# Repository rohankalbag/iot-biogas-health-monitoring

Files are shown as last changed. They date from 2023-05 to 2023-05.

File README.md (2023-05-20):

# IoT-based Biogas Plant Health Monitoring
 
## EE-344 : Electronics Design Lab

- *An IoT-based monitoring system for a biogas plant that measures and displays parameters such as gas concentrations, humidity, and temperature* 

- *The design consists of a tailor-made custom in-house designed two-layer printed circuit board interfacing gas sensors in a modular fashion using I2C*

- *The data is sent to a central server and stored in a cloud database for remote access and analysis through a web application. The system helps optimize biogas production, identify issues, improve safety, and offers flexibility to integrate additional gas sensors. Furthermore, we successfully addressed anticipated problems during development and prototyping stages and submitted a complete market-ready product*

plant_sys

pcb

## [Link to Video Demonstrations](https://youtube.com/playlist?list=PLU3_Wxvmc-mbm3Yfq669lL-GAWkqmuRJW)

## [Link to Detailed Report](https://github.com/rohankalbag/iot-biogas-health-monitoring/blob/chusaro/Report.pdf)

## Recipient of "Best Project Award"

award

## Contributors : Team TUE-23 : Project 18
- Jujhaar Singh
- Sankalp Bhamare
- Rohan Rajesh Kalbag

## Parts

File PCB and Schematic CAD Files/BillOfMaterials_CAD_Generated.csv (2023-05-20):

Part | Value | Device | Package | Description | AVAILABILITY | CATEGORY | CONTACTS | CURRENT_RATING | DESCRIPTION | GENDER | MANUFACTURER | MAXIMUM_PACKAGE_HEIGHT | MF | MOUNT_TYPE | MP | MPN | OPERATING_TEMP | PACKAGE | PARTREV | PART_STATUS | PRICE | ROHS_COMPLIANT | SERIES | SNAPEDA_PACKAGE_ID | SNAPEDA_PN | STANDARD | SUB-CATEGORY | TYPE | VOLTAGE_RATING
C1 | 100nF | CAPACITOR_SMD_1206 | C1206
C2 | 100nF | CAPACITOR_SMD_1206 | C1206
C3 | 100nF | CAPACITOR_SMD_1206 | C1206
C4 | 100nF | CAPACITOR_SMD_1206 | C1206
C5 | 100nF | CAPACITOR_SMD_1206 | C1206
C6 | 100nF | CAPACITOR_SMD_1206 | C1206
C9 | 100nF | CAPACITOR_SMD_1206 | C1206
C10 | 100nF | CAPACITOR_SMD_1206 | C1206
C11 | 100nF | CAPACITOR_SMD_1206 | C1206
C12 | 100nF | CAPACITOR_SMD_1206 | C1206
J1 | 61729-1011 | 61729-1011 | 61729-1011BLF | USB(2.0) Type-B, RCPT, 4POS, THT-R/A |  | Connector | 4 | 1A | CONN RCPT USB2.0 TYPEB 4POS R/A | Receptacle | Amphenol ICC (FCI) |  |  | R/A |  | 61729-1011BLF | -55°C to 85°C |  |  | Active |  | RoHS Compliant | 61729 |  |  |  | USB | USB-B
J2 | 1722991304 | 1722991304 | MOLEX_1722991304 |  |  |  |  |  |  |  | Molex | 14.0 mm |  |  |  |  |  |  | B8 |  |  |  |  |  |  | Manufacturer Recommendations
J3 | 1722991304 | 1722991304 | MOLEX_1722991304 |  |  |  |  |  |  |  | Molex | 14.0 mm |  |  |  |  |  |  | B8 |  |  |  |  |  |  | Manufacturer Recommendations
J4 | 1722991304 | 1722991304 | MOLEX_1722991304 |  |  |  |  |  |  |  | Molex | 14.0 mm |  |  |  |  |  |  | B8 |  |  |  |  |  |  | Manufacturer Recommendations
J5 | 1722991304 | 1722991304 | MOLEX_1722991304 |  |  |  |  |  |  |  | Molex | 14.0 mm |  |  |  |  |  |  | B8 |  |  |  |  |  |  | Manufacturer Recommendations
LS1 | PS1240P02BT | PS1240P02BT | XDCR_PS1240P02BT | Buzzers Transducer, Externally Driven Piezo 3V 4kHz 60dB @ 3V, 10cm Through Hole PC Pins | Unavailable |  |  |  | Buzzers Transducer, Externally Driven Piezo 3V 4kHz 60dB @ 3V, 10cm Through Hole PC Pins |  |  | 7.0mm | TDK |  | PS1240P02CT3 |  |  | SIP-5 TDK |  |  | None
Q1 | BSS138 | BSS138 | SOT95P240X111-3N | N-Channel 50V 220mA (Ta) 360mW (Ta) Surface Mount SOT-23-3 |  |  |  |  |  |  | ON Semiconductor | 1.11 mm |  |  |  |  |  |  | 30 Jan 2018 |  |  |  |  |  |  | IPC 7351B
Q2 | BSS138 | BSS138 | SOT95P240X111-3N | N-Channel 50V 220mA (Ta) 360mW (Ta) Surface Mount SOT-23-3 |  |  |  |  |  |  | ON Semiconductor | 1.11 mm |  |  |  |  |  |  | 30 Jan 2018 |  |  |  |  |  |  | IPC 7351B
Q3 | BSS138 | BSS138 | SOT95P240X111-3N | N-Channel 50V 220mA (Ta) 360mW (Ta) Surface Mount SOT-23-3 |  |  |  |  |  |  | ON Semiconductor | 1.11 mm |  |  |  |  |  |  | 30 Jan 2018 |  |  |  |  |  |  | IPC 7351B
R1 | 10k | RESISTOR_SMD_1206 | M1206
R2 | 1K | RESISTOR_SMD_1206 | M1206
R3 | 1k | RESISTOR_SMD_1206 | M1206
R4 | 10k | RESISTOR_SMD_1206 | M1206
R5 | 470E | RESISTOR_SMD_1206 | M1206
R6 | 470E | RESISTOR_SMD_1206 | M1206
R7 | 470E | RESISTOR_SMD_1206 | M1206
R8 | 10k | RESISTOR_SMD_1206 | M1206
R9 | 10k | RESISTOR_SMD_1206 | M1206
R10 | 10k | RESISTOR_SMD_1206 | M1206
R11 | 10k | RESISTOR_SMD_1206 | M1206
R12 | 10k | RESISTOR_SMD_1206 | M1206
R13 | 10k | RESISTOR_SMD_1206 | M1206
R14 | 10k | RESISTOR_SMD_1206 | M1206
R15 | 10k | RESISTOR_SMD_1206 | M1206
S3 | TS04-66-55-BK-260-SMT | TS04-66-55-BK-260-SMT | SW_TS04-66-55-BK-260-SMT |  |  |  |  |  |  |  | CUI Devices |  |  |  |  |  |  |  | 1.0 |  |  |  |  |  |  | Manufacturer Recommendations
S4 | TS04-66-55-BK-260-SMT | TS04-66-55-BK-260-SMT | SW_TS04-66-55-BK-260-SMT |  |  |  |  |  |  |  | CUI Devices |  |  |  |  |  |  |  | 1.0 |  |  |  |  |  |  | Manufacturer Recommendations
T1 | BC847 | BC847 | SOT23 | NPN TRANSISTOR
T2 | BC847 | BC847 | SOT23 | NPN TRANSISTOR
U1 | ESP32-WROOM-32 | ESP32-WROOM-32 | MODULE_ESP32-WROOM-32 |  |  |  |  |  |  |  | Espressif Systems | 3.2 mm |  |  |  |  |  |  | 2.9 |  |  |  |  |  |  | Manufacturer Recommendations
U2 | AMS1117-3.3 | AMS1117-3.3 | SOT229P700X180-4N |  |  |  |  |  |  |  | Advanced Monolithic Systems | 1.8 mm |  |  |  |  |  |  | N/A |  |  |  |  | 71280 | AMS1117-3.3 | IPC 7351B
U3 | CH340G | CH340G | SOIC127P600X180-16N |  |  |  |  |  |  |  | WCH | 1.8 mm |  |  |  |  |  |  | 2G |  |  |  |  |  |  | IPC 7351B

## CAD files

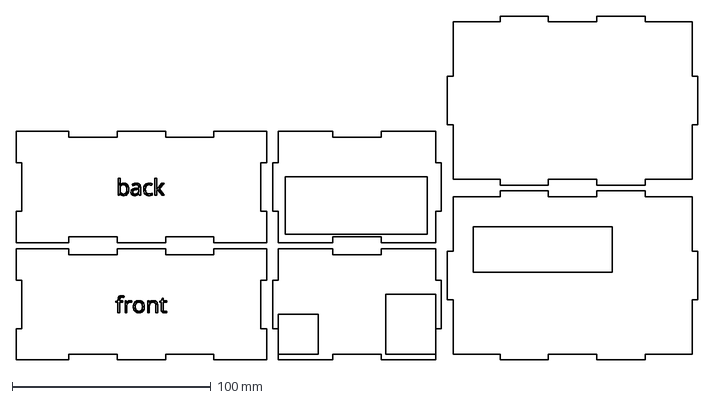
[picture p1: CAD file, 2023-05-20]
Enclosure CAD Files/TUES-23-ENCLOSURE.dxf
343.0 x 173.0 mm

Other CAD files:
Enclosure CAD Files/TUES-23-ENCLOSURE.f3d

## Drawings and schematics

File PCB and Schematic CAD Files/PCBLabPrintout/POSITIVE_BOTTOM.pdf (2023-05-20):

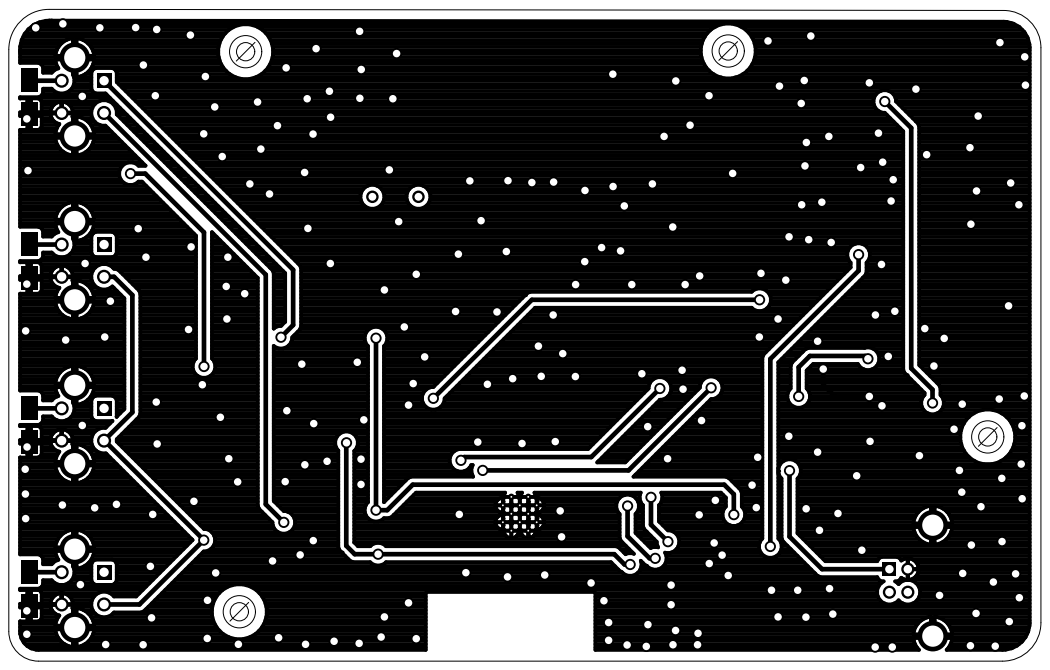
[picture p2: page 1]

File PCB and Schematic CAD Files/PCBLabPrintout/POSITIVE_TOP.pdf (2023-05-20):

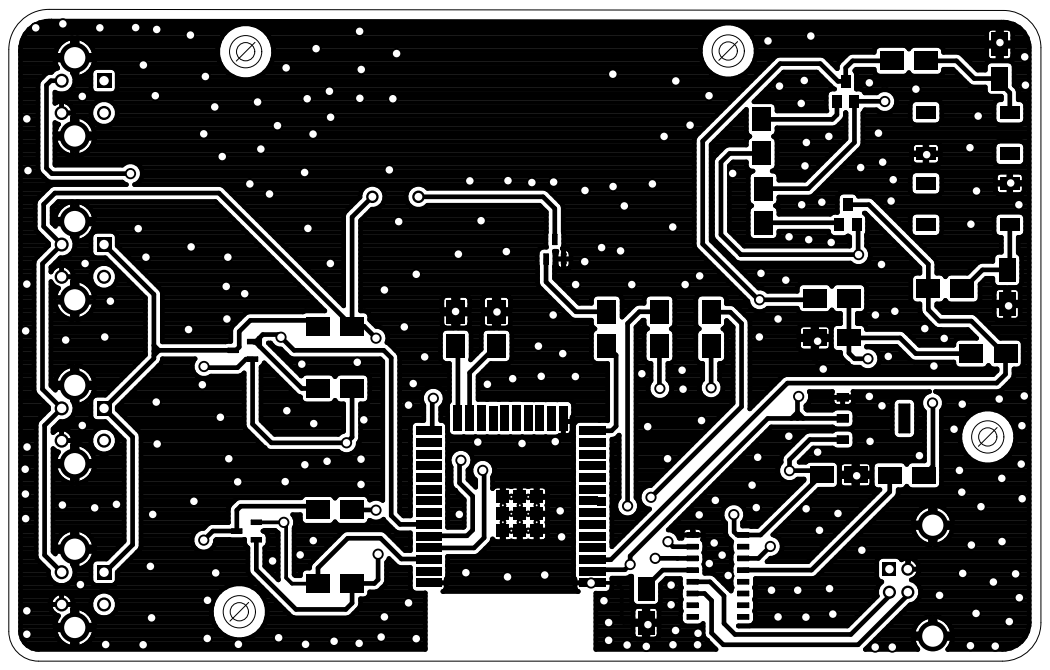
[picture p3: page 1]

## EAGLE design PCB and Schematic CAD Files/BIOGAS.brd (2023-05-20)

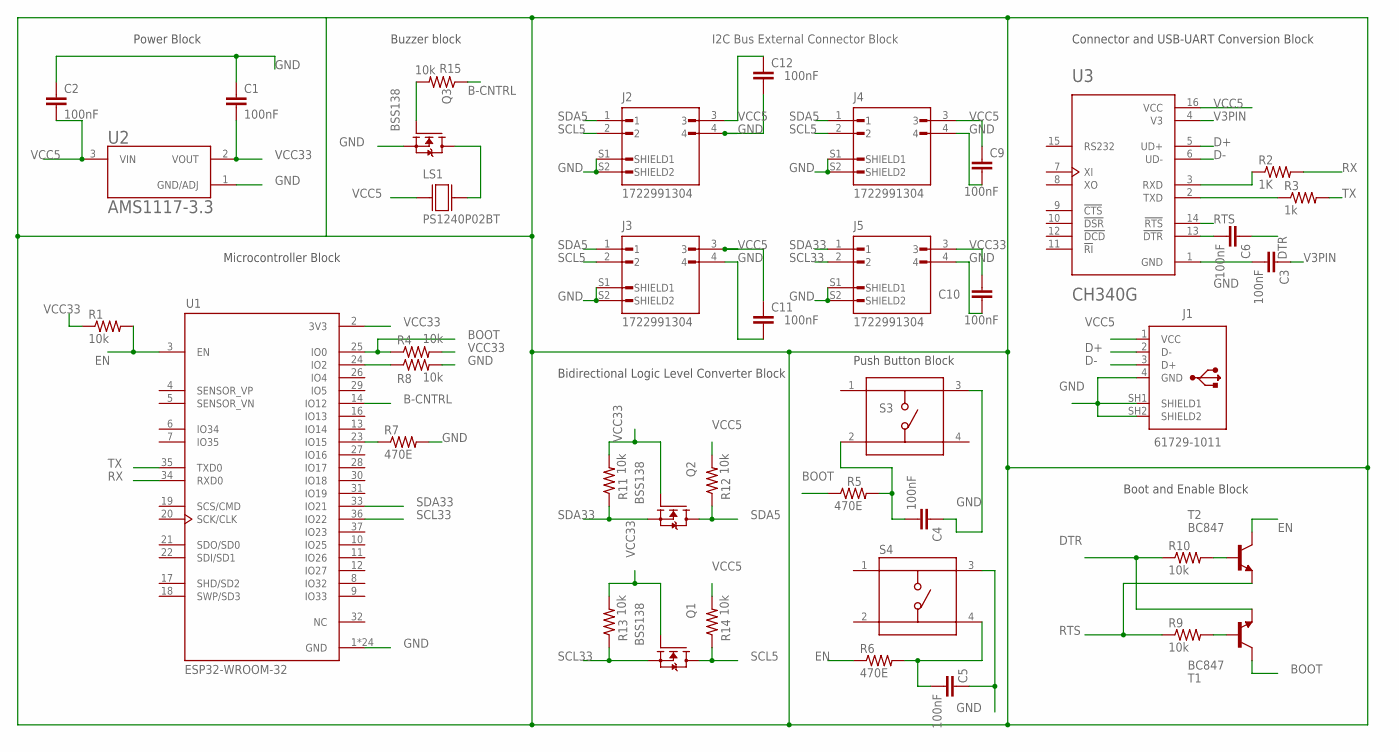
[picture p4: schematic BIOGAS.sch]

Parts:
C1, C2, C3, C4, C5, C6, C9, C10, C11, C12: 100nF; C1206
J1: 61729-1011; 61729-1011BLF
J2, J3, J4, J5: 1722991304; MOLEX_1722991304
LS1: PS1240P02BT; XDCR_PS1240P02BT
Q1, Q2, Q3: BSS138; SOT95P240X111-3N
R1, R4, R8, R9, R10, R11, R12, R13, R14, R15: 10k; M1206
R2: 1K; M1206
R3: 1k; M1206
R5, R6, R7: 470E; M1206
S3, S4: TS04-66-55-BK-260-SMT; SW_TS04-66-55-BK-260-SMT
T1, T2: BC847; SOT23
U1: ESP32-WROOM-32; MODULE_ESP32-WROOM-32
U2: AMS1117-3.3; SOT229P700X180-4N
U3: CH340G; SOIC127P600X180-16N

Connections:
B-CNTRL: R15.1, U1.14 (IO12)
BOOT: R4.1, R5.1, T1.3 (C), U1.25 (IO0)
D+: J1.2 (D-), U3.5 (UD+)
D-: J1.3 (D+), U3.6 (UD-)
DTR: C6.1, R10.1, T1.2 (E)
EN: R1.2, R6.1, T2.3 (C), U1.3 (EN)
GND: C1.1, C2.1, C3.2, C4.1, C5.1, C9.2, C10.2, C11.2, C12.2, J1.4 (GND), J1.SH1 (SHIELD1), J1.SH2 (SHIELD2), J2.4, J2.S1 (SHIELD1), J2.S2 (SHIELD2), J3.4, J3.S1 (SHIELD1), J3.S2 (SHIELD2), J4.4, J4.S1 (SHIELD1), J4.S2 (SHIELD2), J5.4, J5.S1 (SHIELD1), J5.S2 (SHIELD2), Q3.2 (S), R7.2, R8.2, S3.3, S4.3, U1.1 (GND), U1.15 (GND), U1.38 (GND), U1.39_1 (GND), U1.39_2 (GND), U1.39_3 (GND), U1.39_4 (GND), U1.39_5 (GND), U1.39_6 (GND), U1.39_7 (GND), U1.39_8 (GND), U1.39_9 (GND), U1.39_10 (GND), U1.39_11 (GND), U1.39_12 (GND), U1.39_13 (GND), U1.39_14 (GND), U1.39_15 (GND), U1.39_16 (GND), U1.39_17 (GND), U1.39_18 (GND), U1.39_19 (GND), U1.39_20 (GND), U1.39_21 (GND), U2.1 (GND/ADJ), U3.1 (GND)
unnamed: R8.1, U1.24 (IO2)
unnamed: R2.1, U3.3 (RXD)
unnamed: R3.1, U3.2 (TXD)
unnamed: C4.2, R5.2, S3.2
unnamed: C5.2, R6.2, S4.4
unnamed: R7.1, U1.23 (IO15)
unnamed: C6.2, U3.13 (!DTR)
unnamed: R10.2, T2.1 (B)
unnamed: R9.2, T1.1 (B)
unnamed: LS1.2, Q3.3 (D)
unnamed: Q3.1 (G), R15.2
RTS: R9.1, T2.2 (E), U3.14 (!RTS)
RX: R2.2, U1.34 (RXD0)
SCL5: J2.2, J3.2, J4.2, Q1.3 (D), R14.1
SCL33: J5.2, Q1.2 (S), R13.1, U1.36 (IO22)
SDA5: J2.1, J3.1, J4.1, Q2.3 (D), R12.1
SDA33: J5.1, Q2.2 (S), R11.1, U1.33 (IO21)
TX: R3.2, U1.35 (TXD0)
V3PIN: C3.1, U3.4 (V3)
VCC5: C2.2, C9.1, C11.1, C12.1, J1.1 (VCC), J2.3, J3.3, J4.3, LS1.1, R12.2, R14.2, U2.3 (VIN), U3.16 (VCC)
VCC33: C1.2, C10.1, J5.3, Q1.1 (G), Q2.1 (G), R1.1, R4.2, R11.2, R13.2, U1.2 (3V3), U2.2 (VOUT)

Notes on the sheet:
Bidirectional Logic Level Converter Block
Boot and Enable Block
Connector and USB-UART Conversion Block
I2C Bus External Connector Block
Power Block
Microcontroller Block
Push Button Block
Buzzer block

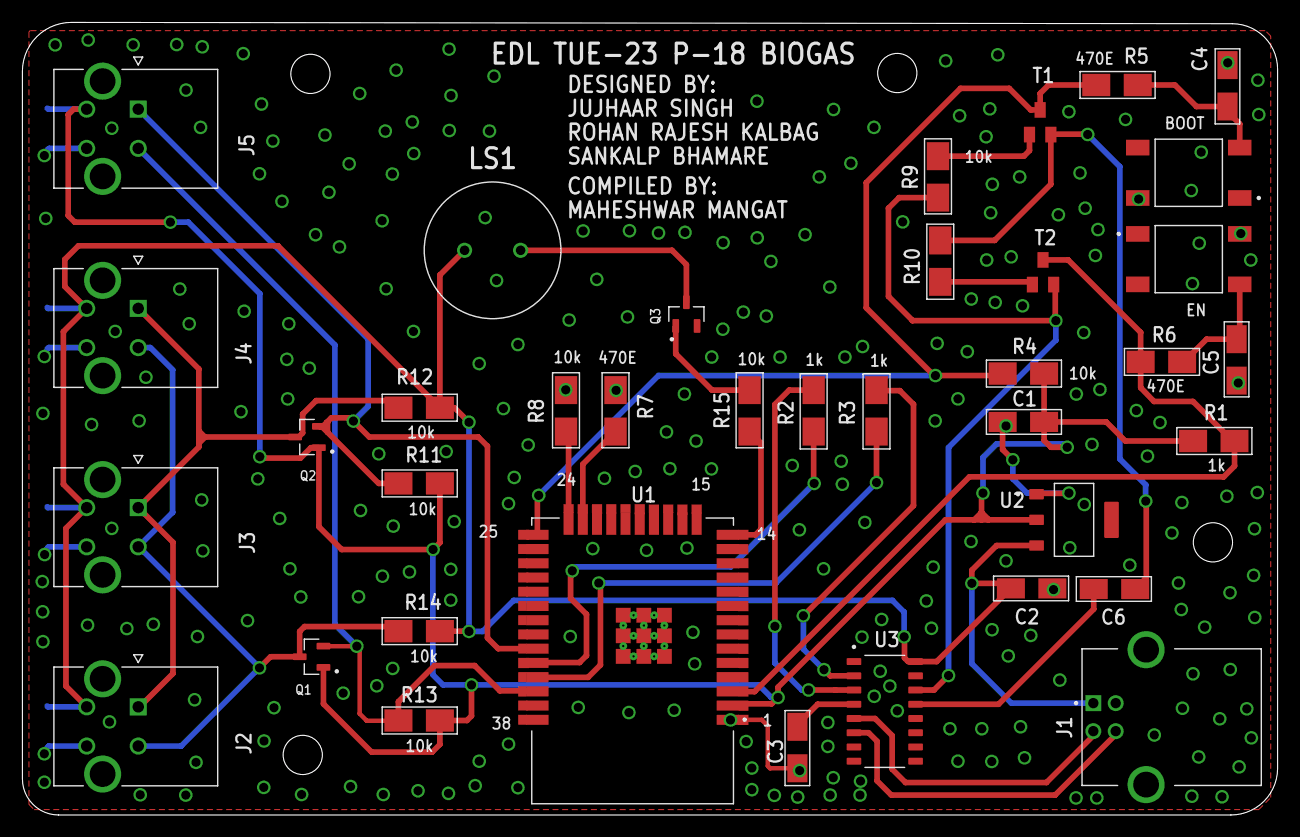
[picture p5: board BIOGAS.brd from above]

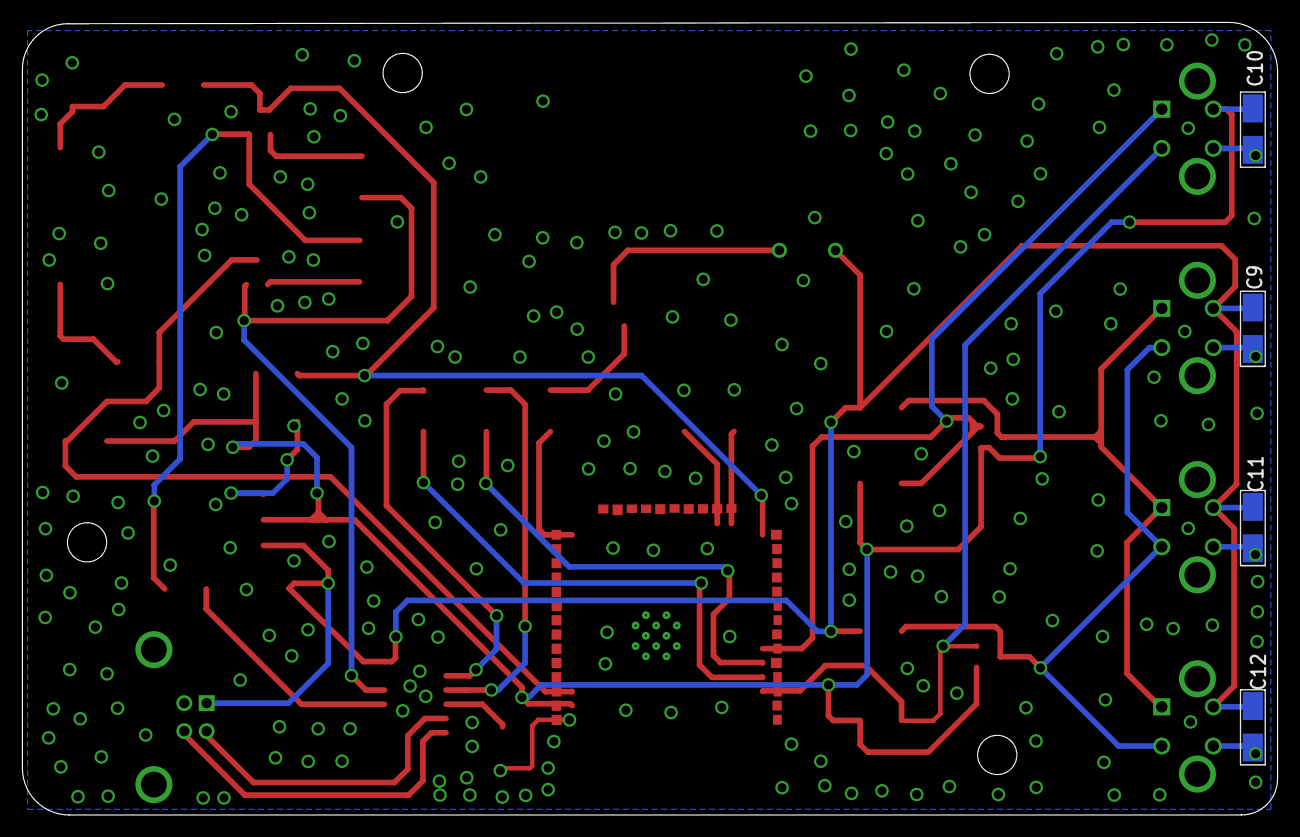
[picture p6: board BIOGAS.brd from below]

Board: 2 copper layers, 112.0 x 70.7 mm, 41 parts (4 on the bottom side), 28 nets.

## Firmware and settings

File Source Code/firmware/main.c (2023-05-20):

// Electronic Design Lab EE 344 IIT Bombay
// Team Tue: 23 
// Authors: Sankalp Bhamare, Rohan Rajesh Kalbag, Jujhaar Singh

#include "server_conn.h"
#include "drivers/i2c_conn.h"

// sensor threshold value, sensor rings after co2 value exceeds threshold

#define SENSOR_THRESHOLD 3000

static const char *TAG = "BioGAS";

void app_main(void)
{
    esp_err_t ret;
    ret = nvs_flash_init();
    if (ret == ESP_ERR_NVS_NO_FREE_PAGES || ret == ESP_ERR_NVS_NEW_VERSION_FOUND)
    {
        ESP_ERROR_CHECK(nvs_flash_erase());
        ret = nvs_flash_init();
    }
    ESP_LOGI(TAG, "SYSTEM BOOTED");

    ESP_LOGI(TAG, "I2C init start");
    init_i2c();
    ESP_LOGI(TAG, "Connecting LCD....");
    init_lcd();
    ESP_LOGI(TAG, "LCD CONNECTED");
    begin_lcd();

    // Basic User Interface on the LCD

    printstr_lcd("EDL P-18");
    setCursor_lcd(0, 1);
    printstr_lcd("TUE-23");
    vTaskDelay(2000 / portTICK_PERIOD_MS);
    setCursor_lcd(0, 1);
    printstr_lcd("Sankalp");
    vTaskDelay(2000 / portTICK_PERIOD_MS);
    setCursor_lcd(0, 1);
    printstr_lcd("Jujhaar");
    vTaskDelay(2000 / portTICK_PERIOD_MS);
    setCursor_lcd(0, 1);
    printstr_lcd("Rohan   ");
    vTaskDelay(2000 / portTICK_PERIOD_MS);

    setCursor_lcd(0, 1);
    printstr_lcd("WiFi Init..");

    ESP_LOGI(TAG, "initializing WiFi module.");
    ret = wifi_init_sta();
    
    if (ret != ESP_OK)
    {
        ESP_LOGE(TAG, "WiFi initialization failed!");
        for (;;)
        {}
    }

    // After WiFi connection is established
    setCursor_lcd(0, 1);
    printstr_lcd("WiFi Connected");

    vTaskDelay(4000 / portTICK_PERIOD_MS);

    setCursor_lcd(0, 1);
    printstr_lcd("System Start");

    vTaskDelay(4000 / portTICK_PERIOD_MS);
    ESP_LOGI(TAG, "WiFi module initialized.");

    // uncomment below line if you want to use LCD backlight
    // backlight_lcd(); 

    init_buzzer(); // initialize buzzer
    for (;;)
    {
        // read co2 sensor data
        int co2_ppm = read_co2_ppm();
        // conditional to check if the sensor reading is under threshold
        if (co2_ppm > SENSOR_THRESHOLD)
        {
            buzzer_toggle(true);
        }
        else
        {
            buzzer_toggle(false);
        }

        double temp, rel_humidity;
        // read the dht sensor values
        read_dht(&rel_humidity, &temp);
        // send sensor readings to web server
        render_screen(co2_ppm, rel_humidity);
        http_post_task(co2_ppm, rel_humidity);
        ESP_LOGI(TAG, "HTTP DATA PUSHED");
    }
    denit_i2c();
    vTaskDelay(10);
}

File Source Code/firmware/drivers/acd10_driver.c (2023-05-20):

// Electronic Design Lab EE 344 IIT Bombay
// Team Tue: 23 
// Authors: Sankalp Bhamare, Rohan Rajesh Kalbag, Jujhaar Singh

// drivers for the acd10 co2 sensor

#include "acd10_driver.h"

int read_co2_ppm()
{ 
  // function to read the co2 sensor readings
  uint8_t read_cmd[2] = {0x03, 0x00};

  uint8_t i2c_buffer_out[9];
  char buffer_out[9];
  ESP_ERROR_CHECK(i2c_master_write_to_device(I2C_MASTER_NUM, ACD_ADDRESS, read_cmd, 2, I2C_MASTER_TIMEOUT_MS / portTICK_PERIOD_MS));
  ESP_ERROR_CHECK(i2c_master_read_from_device(I2C_MASTER_NUM, ACD_ADDRESS, i2c_buffer_out, 9, I2C_MASTER_TIMEOUT_MS / portTICK_PERIOD_MS));

  for (int i = 0; i < 9; i++)
  {
    buffer_out[i] = i2c_buffer_out[i];
  }
  ESP_LOGI("ACD10", "\n[PPM3]\t[PPM2]\t[CRC1]\t[PPM1]\t[PPM0]\t[CRC2]\t[D1]\t[D2]\t[CRC3]\n%02X\t%02X\t%02X\t%02X\t%02X\t%02X\t%02X\t%02X\t%02X\t", buffer_out[0], buffer_out[1], buffer_out[2], buffer_out[3], buffer_out[4], buffer_out[5], buffer_out[6], buffer_out[7], buffer_out[8]);

  ESP_LOGI("ACD10", "\n[CRC1]\t[CRC2]\t[CRC3]\n%s\t%s\t%s", Calc_CRC8(buffer_out, 2) == buffer_out[2] ? "MATCH" : "FAIL", Calc_CRC8(buffer_out + 3, 2) == buffer_out[5] ? "MATCH" : "FAIL", Calc_CRC8(buffer_out + 6, 2) == buffer_out[8] ? "MATCH" : "FAIL");
  int co2_ppm = (((((int)buffer_out[0]) * 256 + buffer_out[1]) * 256 + buffer_out[3]) * 256) + buffer_out[4];
  ESP_LOGI("ACD10", "CO2[PPM]: %d\n", co2_ppm);
  return co2_ppm;
}

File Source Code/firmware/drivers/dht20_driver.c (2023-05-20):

// Electronic Design Lab EE 344 IIT Bombay
// Team Tue: 23 
// Authors: Sankalp Bhamare, Rohan Rajesh Kalbag, Jujhaar Singh

// drivers to read from the DHT10 humidity sensor

#include "dht20_driver.h"

void read_dht(double *hum_out, double *temp_out)
{
  uint8_t read_cmd[3] = {0xAC, 0x33, 0x00};

  uint8_t i2c_buffer_out[9];
  char buffer_out[7];
  ESP_ERROR_CHECK(i2c_master_write_to_device(I2C_MASTER_NUM, DHT_ADDRESS, read_cmd, 3, I2C_MASTER_TIMEOUT_MS / portTICK_PERIOD_MS));
  while(true) {
    ESP_ERROR_CHECK(i2c_master_read_from_device(I2C_MASTER_NUM, DHT_ADDRESS, i2c_buffer_out, 1, I2C_MASTER_TIMEOUT_MS / portTICK_PERIOD_MS));
    if (i2c_buffer_out[0] & 0x80) break;
  }
  ESP_ERROR_CHECK(i2c_master_read_from_device(I2C_MASTER_NUM, DHT_ADDRESS, i2c_buffer_out, 7, I2C_MASTER_TIMEOUT_MS / portTICK_PERIOD_MS));

  for (int i = 0; i < 7; i++)
  {
    buffer_out[i] = i2c_buffer_out[i];
  }

  char crc = Calc_CRC8(buffer_out, 6);
  if (crc == buffer_out[6]) {
    ESP_LOGI("I2C", "CRC matches, value: %x\n", buffer_out[6]);
  } else {
    ESP_LOGI("I2C", "CRC MISMATCH, value: %x\n", buffer_out[6]);
  }
  
  uint32_t raw_humidity = buffer_out[1];
  raw_humidity = (raw_humidity<<8) + buffer_out[2];
  raw_humidity = (raw_humidity<<4) +  (buffer_out[3] >> 4 );
  double humidity = raw_humidity/1048576.0 * 100;
  
  uint32_t raw_temp_c = buffer_out[3] & (0x0F);
  raw_temp_c = (raw_temp_c << 8) + buffer_out[4];
  raw_temp_c = (raw_temp_c << 8) + buffer_out[5];
  double temp_c = raw_temp_c/1048576.0*200.0 - 50.0; 

  ESP_LOGI("DHT20", "Relative Humidity[%%]: %.2f\n", humidity);
  ESP_LOGI("DHT20", "Temp[C]: %.2f\n", temp_c);
  *hum_out = humidity;
  *temp_out = temp_c;
}
